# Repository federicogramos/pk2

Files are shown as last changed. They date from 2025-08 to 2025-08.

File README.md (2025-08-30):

# About
Diseño de hardware de programador pk2, una version eliminando lo que no es indispensable del circuito original usado por Microchip, de modo que entre en una placa de tamaño no mas grande que un pendrive. El firmware se brinda sin modificaciones del propio Microchip.

## ./sw
- device file editor: herramienta para adicionar cualquier modelo a la lista de dispositivos programables del pk2.
- codigo fuente + firmware para el 18F2550 (PK2V023200.hex).
- código fuente app pk2 v2.61
- app pk2 linea de comando.

## ./pcb
Contiene 2 diseños:
- el del Pickit2
- un zocalo externo para encapsulados DIP.
Del pcb pendrive estoy subiendo unicamente la última version. Tengo otra que fue el 1er prototipo single layer. Si en algun momento a alguien le interesa porque la fabricacion es más simple y no requiere pth, puede solicitarme que la suba.

#### Pk2 pcb top y bottom
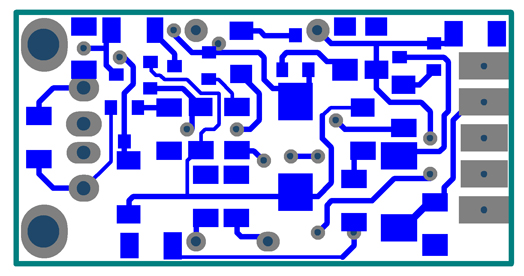
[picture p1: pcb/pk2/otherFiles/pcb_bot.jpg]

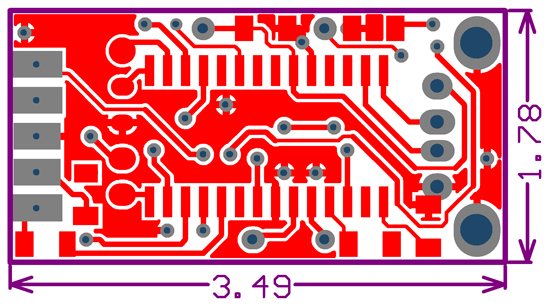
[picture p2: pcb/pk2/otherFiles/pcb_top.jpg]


#### Schematic (pk2 only)
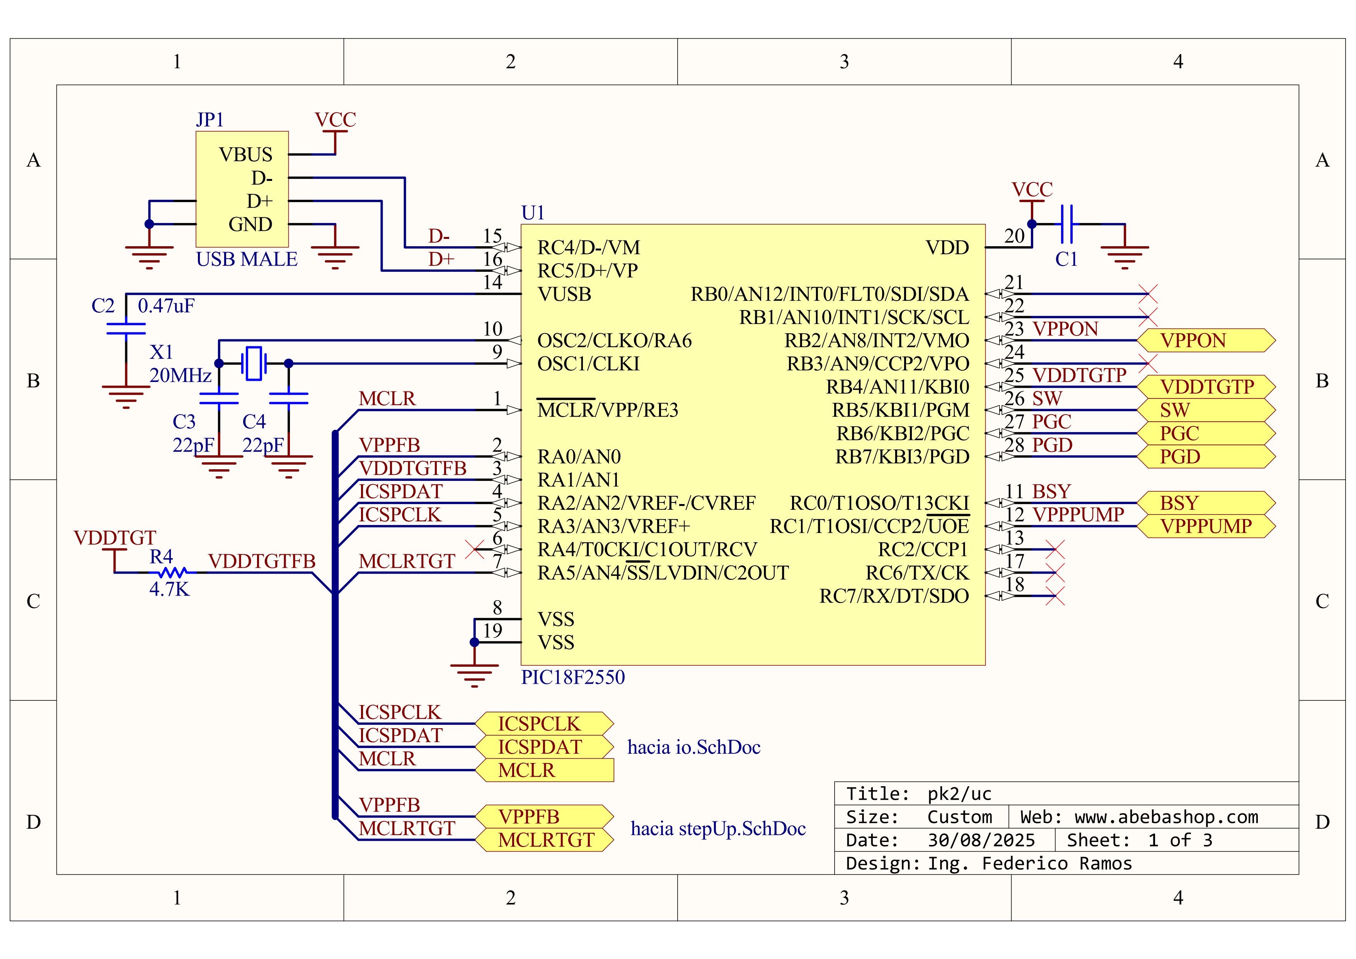
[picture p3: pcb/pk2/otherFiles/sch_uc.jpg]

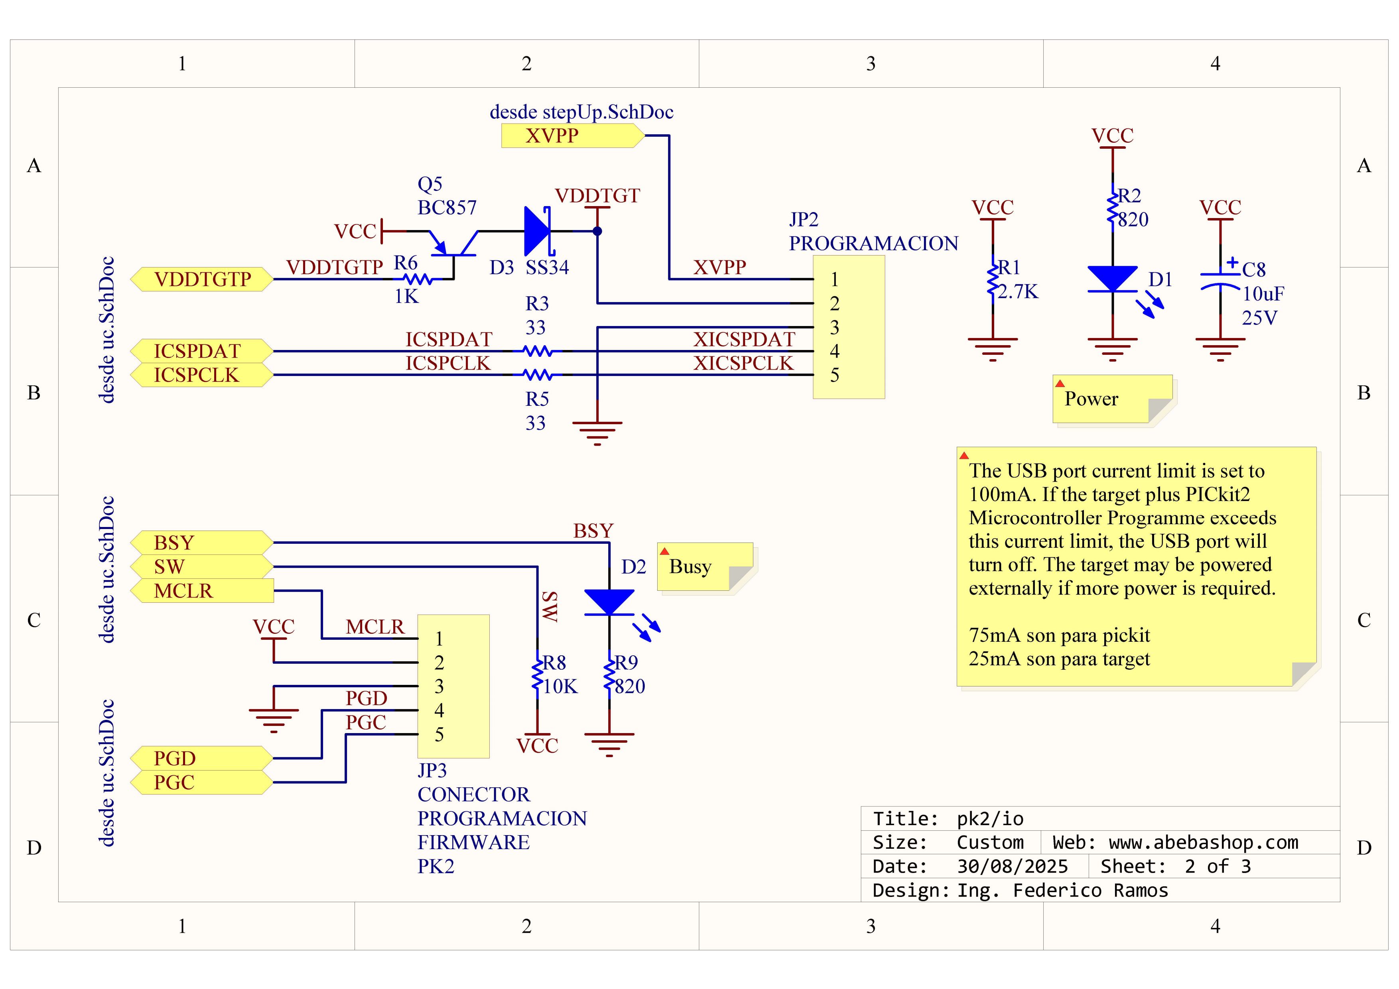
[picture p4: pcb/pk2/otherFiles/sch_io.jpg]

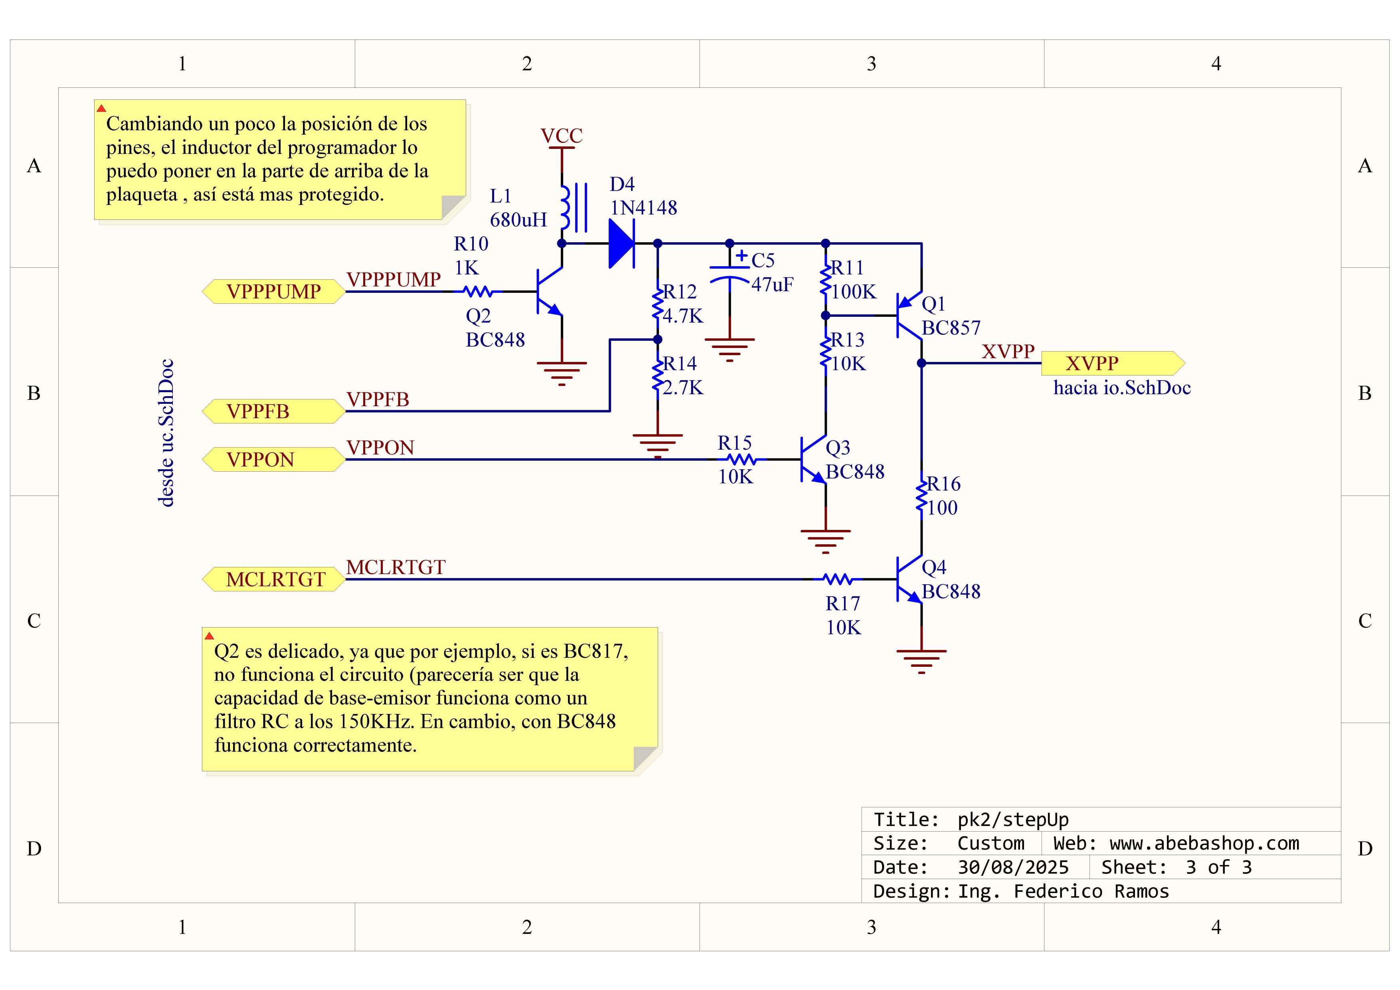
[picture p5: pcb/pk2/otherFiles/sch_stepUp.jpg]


#### Prototipo top y bottom
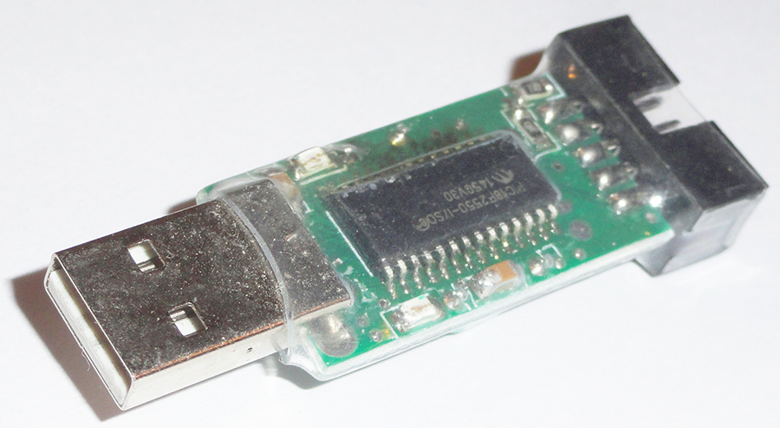
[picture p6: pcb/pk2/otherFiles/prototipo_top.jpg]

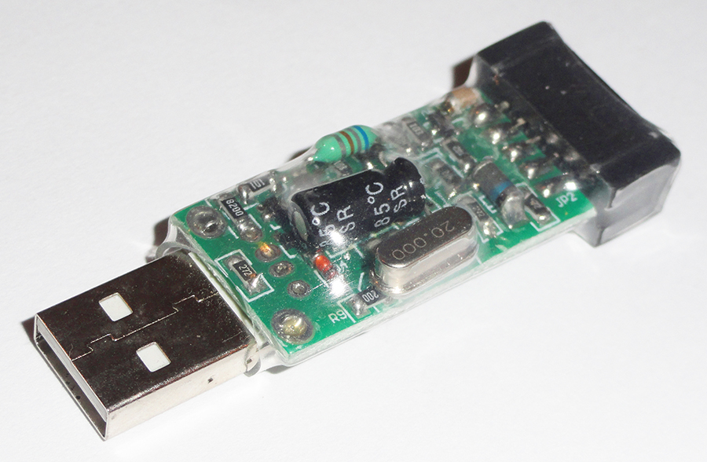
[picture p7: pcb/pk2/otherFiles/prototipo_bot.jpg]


## ./manual
Obsoleto. Antiguamente se entregaba con el dispositivo.

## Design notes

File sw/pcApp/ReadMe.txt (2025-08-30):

Source Notes for PICkit(R) 2 Microcontroller Programmer PC Application v2.60.01

Contains Device File V1.61.00 as
\PICkit2V2\PICkit2V2\bin\Release\PK2DeviceFile.dat

This source project can be opened and modified in Microsoft Visual C# Express 2005.
It requires installation of the Microsoft .NET Framework 2.0

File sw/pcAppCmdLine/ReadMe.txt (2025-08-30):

Source Notes for PICkit(R) 2 Microcontroller Programmer PK2CMD Command Line Interface v1.20

Contains Device File V1.55.00 as
pk2cmd\release\PK2DeviceFile.dat

This source project can be opened and modified in Microsoft Visual C++ 2005 Express.

The included Source Guide is written more for the PICkit 2 Programmer GUI sofware, but generally applies to the PK2CMD source as well.  (Note that PK2CMD does not make any use the INI file described therein.)
NOTE: Descriptions in the Device File section regarding 9th config word support are not applicable to PK2CMD v1.20 as it does not yet support 9 configuration word devices.

This source is set up for Windows development of PK2CMD in Visual Studio, although all source files necessary for Linux and Mac OS builds are also included.  However, for building on these OS's it is recommended to download the v1.20 source titled specifically for them, as that archive contains a makefile and documentation specific to those Operating Systems.

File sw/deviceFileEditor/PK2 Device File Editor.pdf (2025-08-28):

# PICkit 2 Device Data File Editor

This program provides a simple interface for editing the device data file PKDeviceFile.dat that comes with the PICkit2 windows programs. It's my first .NET application ever and I won't be surprised if there's a few bugs in it.

I know this is a painfully simple program which probably doesn't require any documentation whatsoever, so only basic notes are provided.

## Program screenshot:

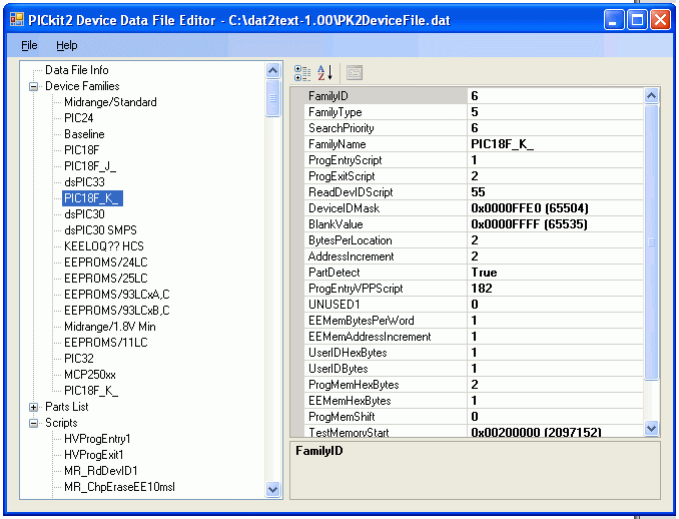
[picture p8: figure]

## Usage

File Menu:
Open - loads and decodes file

Save - overwrites the loaded file with the data in memory
Save As - writes the data in memory to a file of your choosing

Right click on any leaf node (in the left treeview panel) for a popup menu to: Duplicate - make an identical copy of the selected family/part/script
Remove - delete the selected family/part/script

Number formats:
- where a field is displayed as hex (dec), you can enter Hex: e.g. 0xfa44 or &hfa44 or fa44h
Binary: e.g. 0b11110010 or %11110010
Decimal: e.g. 1443
- where a field is displayed as decimal, you can enter Hex: e.g. 0xfa44 or &hfa44
Decimal: e.g. 1443

The program is generally only useful for adding new parts not currently supported by the devicefile bundled with the PICKit 2. The process, after opening the devicefile, is simply to choose an existing PIC from the list of devices, right click on it and select Duplicate Item. There will now be a copy of the part you selected. Change the properties of the new part, including the part name, to appropriate values for the new part. Then save the file and you're done.

It's possible to find the appropriate fields from the datasheet and programming specification documents for the particular PIC part. Sometimes it's a little bit hard to find what you're looking for, or to even know what you should be looking for; feel free to ask on the Microchip Forums (in particular under this thread: PK2 Device File Editor Thread); there's some very knowledgeable and experienced members there. (http://www.microchip.com/forums/m473925-p3.aspx)

There is sometimes updates devicefiles available from Microchip (maybe search the Microchip forums). (http://forum.microchip.com/)

## Downloads

If you already have the .NET 2.0 framework and the VC9 redistributable dll files installed (either in the windows\system32 directory, or in the same directory of this program) you can just download the exe and dll files and the program should run. Or you can use an installer (which I haven't bothered to include for later builds - it's not needed, just copy the exe and dll to the same directory and it should run; provided the VC runtime files are present on the PC).

N.B. VC Runtime files are not required from version 1.0.0.6 onwards.

Version 1.0.0.6 Exe only (.NET 2.0) (https://sites.google.com/site/pk2devicefileeditor/home/files)
Notes: RawConvert.dll (a 32-bit library) dependency has been removed which may allow the program to run under 64 bit Windows.

Version 1.0.0.5 Exe + Dll only (.NET 2.0) (https://sites.google.com/site/pk2devicefileeditor/home/files)
Notes: The serialization bug introduced in 1.0.0.4 has been fixed. DeviceID field is also now displayed as 0xHEX (DEC).

Version 1.0.0.4 Exe + Dll only (.NET 2.0) (https://sites.google.com/site/pk2devicefileeditor/home/files)

Notes: All fields that look like they should be hex are displayed as 0xHEX (DEC); values can be entered as decimal, hex (prefix "0x" or "&H" or suffix "H") or binary (prefix "0b" or "%"). The ScriptLength field is now automatically updated as you change script command array.

Version 1.0.0.3 Exe + Dll only (.NET 2.0) (https://sites.google.com/site/pk2devicefileeditor/home/files)

Notes: The Parts List tree view section is sorted by name. Duplication now actually copies the object data (not just the reference). Fixed the collection explosion bug (probably added some new ones)

Version 1.0.0.2 Installer (.NET 2.0) (https://sites.google.com/site/pk2devicefileeditor/home/files) Version 1.0.0.2 Exe + Dll (.NET 2.0) (https://sites.google.com/site/pk2devicefileeditor/home/files)

Notes: Same as 1.0.0.1, but had to do some mods to let it compile under .NET 2.0 (required to run on the old W2k)

Version 1.0.0.1 Installer (.NET 3.5) (https://sites.google.com/site/pk2devicefileeditor/home/files) Version 1.0.0.1 Exe + Dll (.NET 3.5) (https://sites.google.com/site/pk2devicefileeditor/home/files)

Notes: Proof of concept

Version 1.0.0.0 (.NET 3.5)

Notes: I lost it. It was rubbish anyway so I guess it wasn't really a loss.

MS VC++ Redistributable DLLs (https://sites.google.com/site/pk2devicefileeditor/home/files)
Notes: You may need to download these and extract them to the same directory that you extracted the above .exe + .dll to. Only required if you don't already have them on your PC.

## Bugs (that I know of)

1. Version 1.0.0.3+. Fixed: You'll get a warning if you try to change the configMask & configBlank & script dimensions.
Versions 1.0.0.0 - 1.0.0.2. Workaround: User takes some responsibility for their actions (am I dreaming?) When editing data arrays from the properties editor dialogue, it's possible to add and remove items from the array (and consequently change its size). This could forseeably create an invalid file.
2. Version 1.0.0.3+. Fixed: LeafInfoNode object is now serializable and is cloned for the duplicate operation
Versions 1.0.0.0 - 1.0.0.2. Workaround: you could duplicate all the nodes you want, save the file, then reopen it and edit the nodes
Using the duplicate function creates a new tree node but the actual data is shared between the new node and the old node
3. Version 1.0.0.3+. Fixed: Cut & paste error - I was adding new items to the collections as I was writing them to the file (dumb!)
Versions 1.0.0.0 - 1.0.0.2. Workaround: Just reopen the file, redo the changes and hopefully it works this time.
When duplicating and/or removing nodes after saving a file the number of objects in the families, parts lists and scripts collections double. It only happens after saving the file (which appends to the collections) and then performing a duplicate/remove (which updates the count of items that will later be written to file)
4. Version 1.0.0.5+. Fixed: marked types as serializable
Version 1.0.0.4. int16_t and int32_t data types were not marked as serializable - this meant duplicating an item wasn't possible

Found any new bugs? Please tell me.

## Enhancements

- none planned

## Contact

For info on the PK2 device data file and what to do with it, try the Microchip forums (http://forum.microchip.com/), or more simply PK2 Device File Editor Thread (probably how you found this page) (http://www.microchip.com/forums/m473925-p3.aspx)

To contact me you can try

Sign in (https://www.google.com/a/UniversalLogin?service=jotspot) | Recent Site Activity (https://sites.google.com/site/pk2devicefileeditor/system/app/pages/recentChanges) | Report Abuse (https://sites.google.com/site/pk2devicefileeditor/system/app/pages/reportAbuse) | Print Page | Powered By Google Sites (http://sites.google.com/)

## Comments

You do not have permission to add comments.

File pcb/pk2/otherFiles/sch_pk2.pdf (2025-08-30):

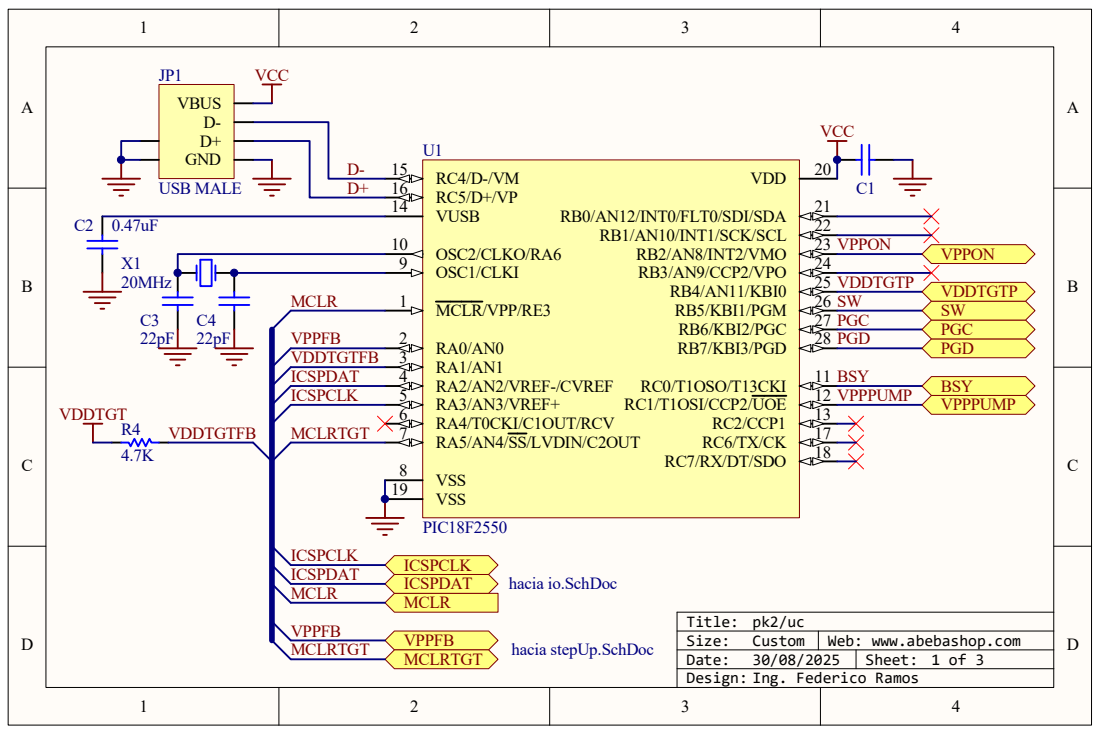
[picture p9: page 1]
MCLR/VPP/RE3 1; RA0/AN0 2 RA1/AN1 3 RA2/AN2/VREF-/CVREF 4 RA3/AN3/VREF+ 5 RA4/T0CKI/C1OUT/RCV 6 RA5/AN4/SS/LVDIN/C2OUT 7; VSS 8; OSC1/CLKI 9; OSC2/CLKO/RA6 10; RC0/T1OSO/T13CKI; RC1/T1OSI/CCP2/UOE; RC2/CCP1; VUSB 14; RC7/RX/DT/SDO; VSS 19; VDD; RB0/AN12/INT0/FLT0/SDI/SDA; RB1/AN10/INT1/SCK/SCL; RB2/AN8/INT2/VMO; RB3/AN9/CCP2/VPO; RB4/AN11/KBI0; RB5/KBI1/PGM; RB6/KBI2/PGC; RB7/KBI3/PGD; PIC18F2550; VCC; 20MHz; VDDTGT; MCLR; PGD; PGC; BSY; VPPFB VDDTGTFB ICSPDAT ICSPCLK; MCLRTGT; VPPON; VPPPUMP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

hacia io.SchDoc

Web: www.abebashop.com

hacia stepUp.SchDoc

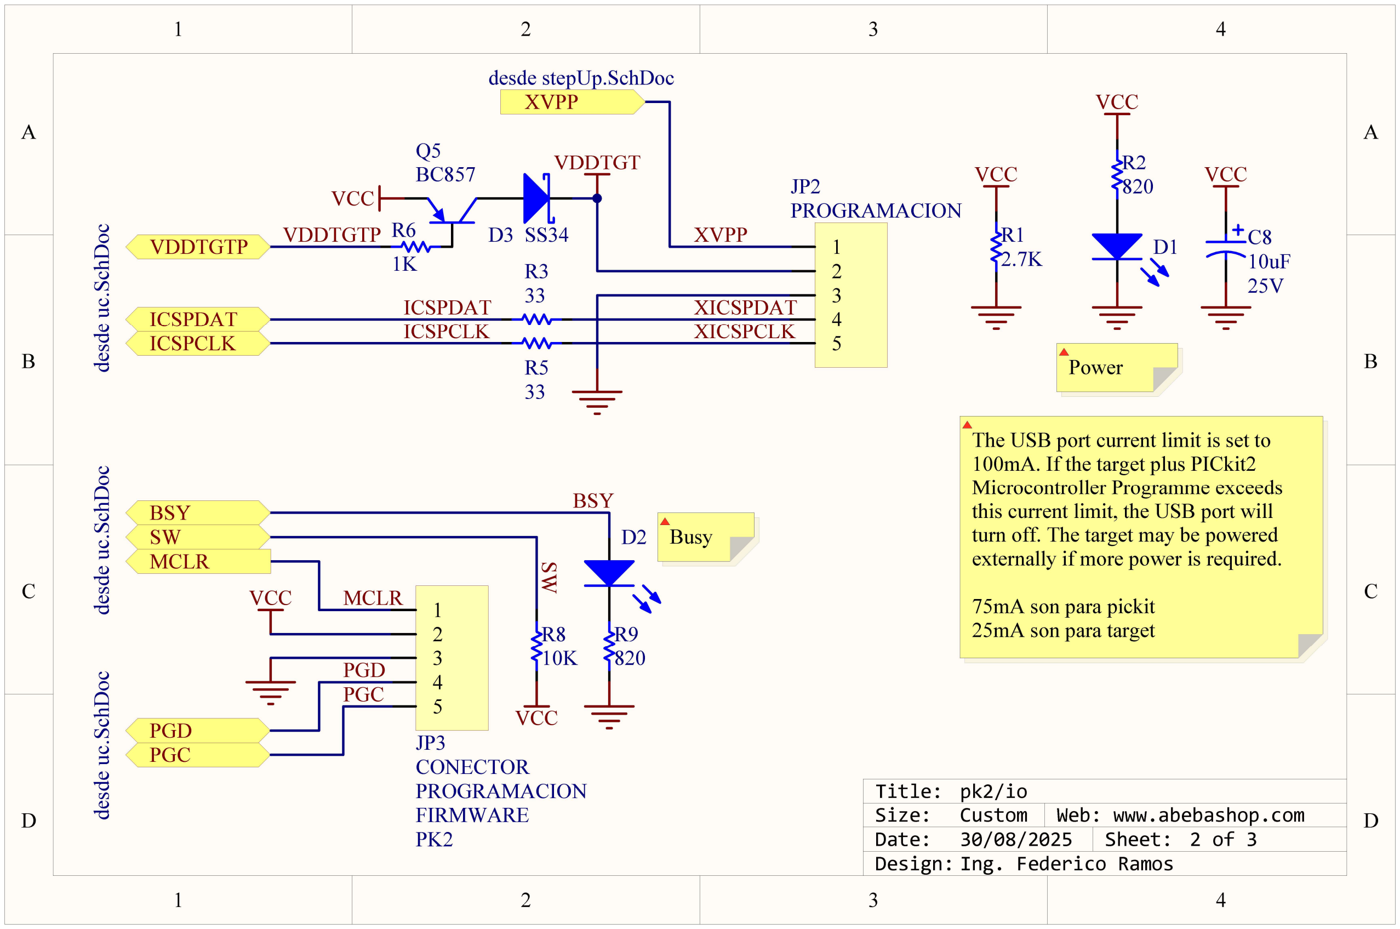
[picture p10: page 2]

D D

C C

B B

A A

VCC | MCLR
| PGD PGC

820

R9

D2

BSY SW

10K

R8

VCC

CONECTOR

1
2
3
4
5

PROGRAMACION
FIRMWARE
PK2

JP3

820

R2

D1

VCC

2.7K

R1

VCC

10uF
25V

C8

VCC

33

R5

33

R3

ICSPCLK

ICSPDAT

VDDTGT

XVPP

XICSPDAT
XICSPCLK

Q5
BC857

VDDTGTP

VCC

1K

R6 D3 SS34

PROGRAMACION
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
MCLR

SW

BSY

VDDTGTP

ICSPDAT
ICSPCLK

XVPP desde uc.SchDoc desde uc.SchDoc desde uc.SchDoc

desde stepUp.SchDoc

Title:
Size:
Date: | Sheet:
Design:

30/08/2025

| Web: www.abebashop.com
| Ing. Federico Ramos

### 2 of 3

pk2/io
Custom

Busy

Power

The USB port current limit is set to 100mA. If the target plus PICkit2 Microcontroller Programme exceeds this current limit, the USB port will turn off. The target may be powered externally if more power is required.

75mA son para pickit
25mA son para target

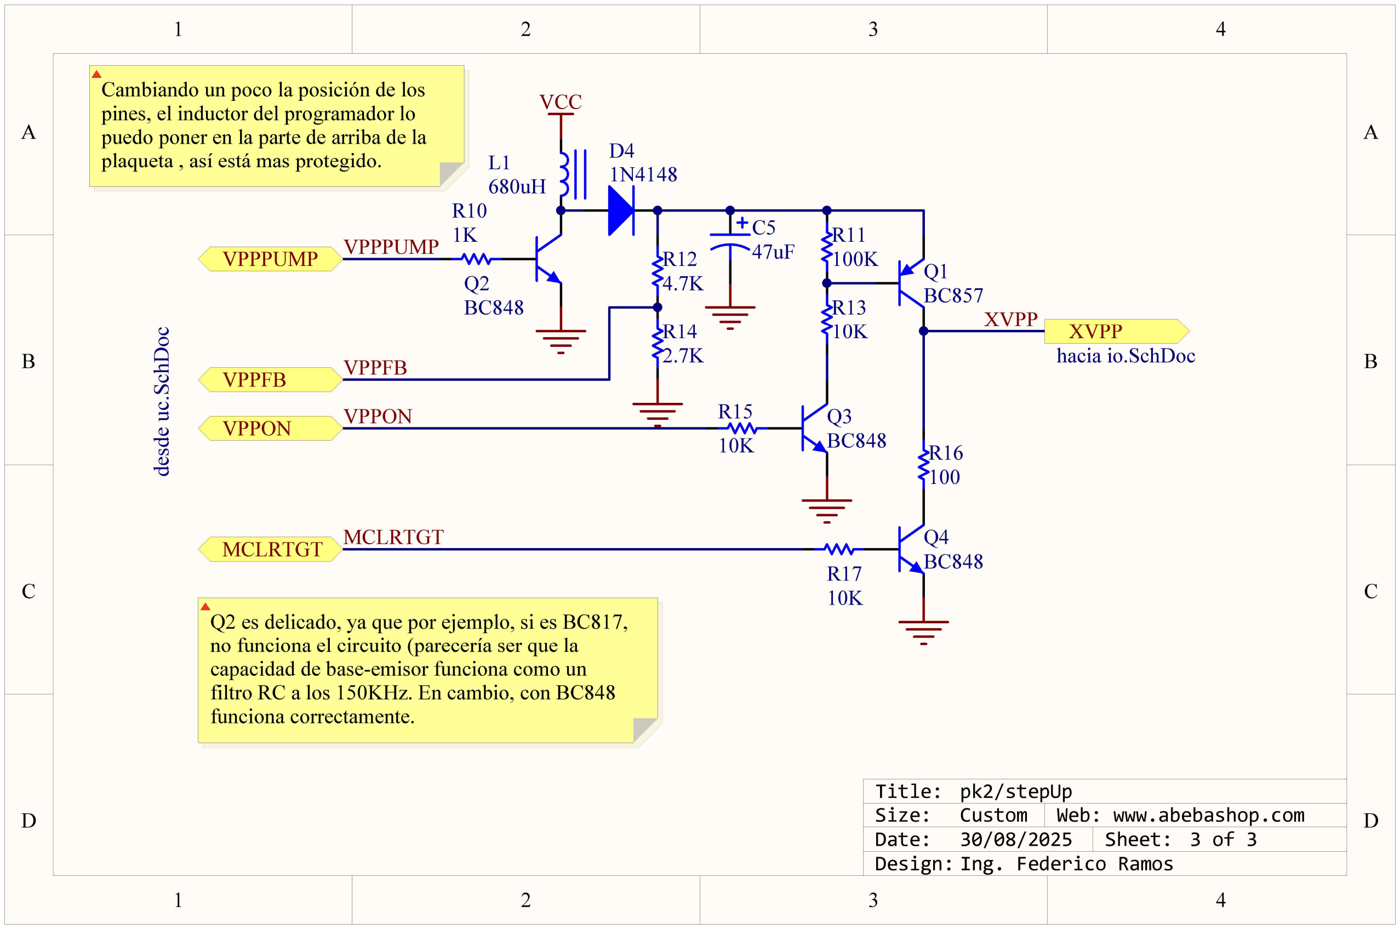
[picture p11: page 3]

D D

C C

B B

A A

680uH

L1

Q2
BC848

1K

R10
VPPPUMP
4.7K

R12

2.7K

R14
VPPFB

100K

R11

10K

R13

Q1
BC857

Q3
10K | BC848
VPPON | R15

100

R16

Q4
BC848
10K

R17

MCLRTGT

D4
1N4148

VCC

C5
47uF

XVPP

VPPPUMP

VPPFB

VPPON

MCLRTGT

XVPP
hacia io.SchDoc desde uc.SchDoc

Title:
Size:
Date: | Sheet:
Design:

30/08/2025

| Web: www.abebashop.com
| Ing. Federico Ramos

### 3 of 3

pk2/stepUp
Custom

Q2 es delicado, ya que por ejemplo, si es BC817, no funciona el circuito (parecería ser que la capacidad de base-emisor funciona como un filtro RC a los 150KHz. En cambio, con BC848 funciona correctamente.

Cambiando un poco la posición de los pines, el inductor del programador lo puedo poner en la parte de arriba de la plaqueta , así está mas protegido.

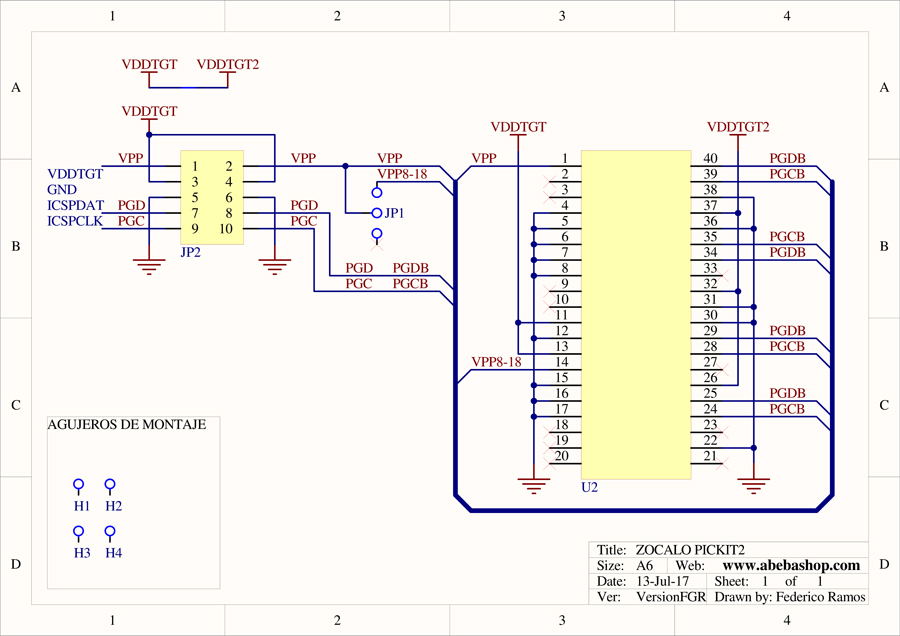
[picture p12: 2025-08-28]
pcb/pk2socket/otherFiles/WEBDOC_IX00000002_N0016.jpg

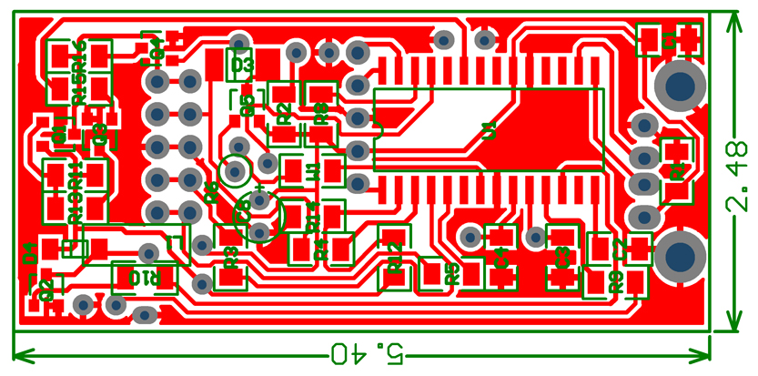
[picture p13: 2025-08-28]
pcb/pk2/otherFiles/WEBDOC_IX00000002_N0001.jpg

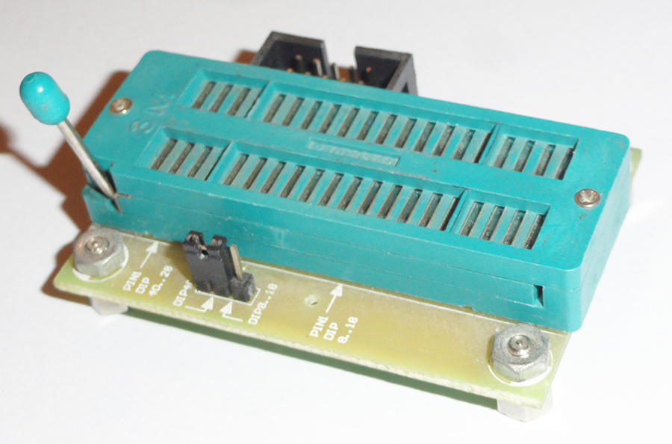
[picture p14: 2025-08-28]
pcb/pk2socket/otherFiles/WEBDOC_IX00000002_N0017.jpg

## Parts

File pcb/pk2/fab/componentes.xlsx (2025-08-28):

Description | Designator | Quantity [x1] | Quantity [x77]
BC846A | Q2, Q3, Q4 | 3 | 372
BC856A | Q1, Q5 | 2 | 248
Capacitor 1206 / 100nF | C1 | 1 | 124
Capacitor 1206 / 470nF | C2 | 1 | 124
Capacitor 1206 / 22pF | C3, C4 | 2 | 248
Capacitor 1206 / 1uF | C8 | 1 | 124
Cristal 20Mhz / HC49S | X1 | 1 | 124
PIC18F2550 | U1 | 1 | 124
IDC Header 5x1 Recto | JP2 | 1 | 124
1N4148 SMD | D4 | 1 | 124
Inductor 680uHy | L1 | 1 | 124
Led 1206 Rojo | D1? | 1 | 124
Led 1206 Amarillo | D2? | 1 | 124
Resistor 1206 / 2.7K | R1, R14 | 2 | 248
Resistor 1206 / 100K | R11 | 1 | 124
Resistor 1206 / 100 | R16 | 1 | 124
Resistor 1206 / 820 | R2, R9 | 2 | 248
Resistor 1206 / 33 | R3, R5 | 2 | 248
Resistor 1206 / 4.7K | R4, R12 | 2 | 248
Resistor 1206 / 1K | R6, R10 | 2 | 248
Resistor 1206 / 10K | R8, R13, R15, R17 | 4 | 496
SS34 | D3 | 1 | 124
Capacitor Electrolitico 47uF / 16V | C5 | 1 | 124
PCB USB 'A' Connector Male | JP1 | 1 | 124

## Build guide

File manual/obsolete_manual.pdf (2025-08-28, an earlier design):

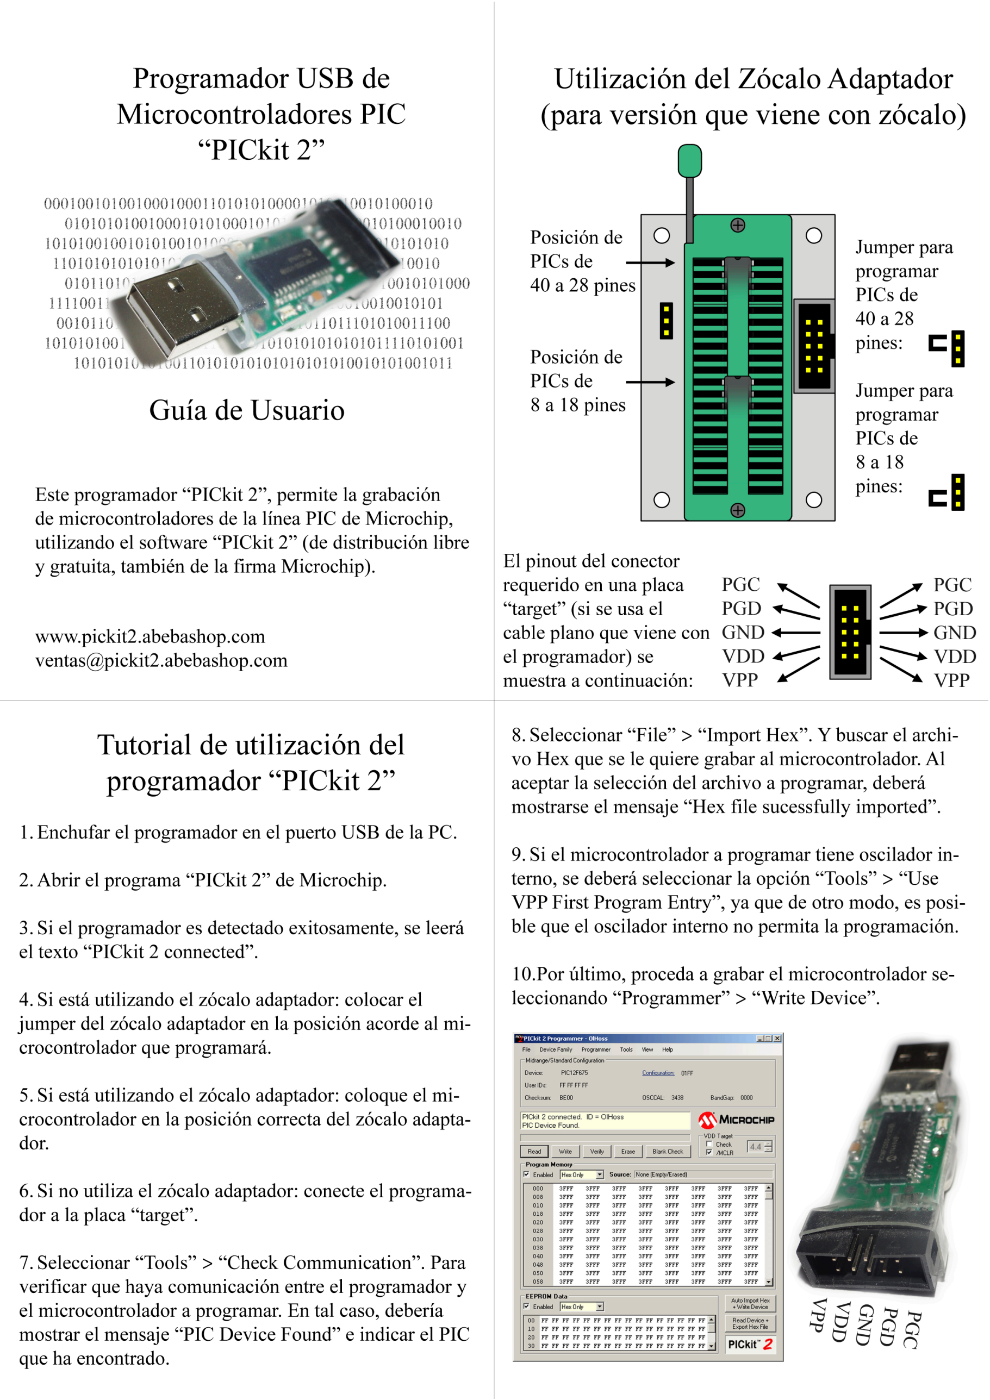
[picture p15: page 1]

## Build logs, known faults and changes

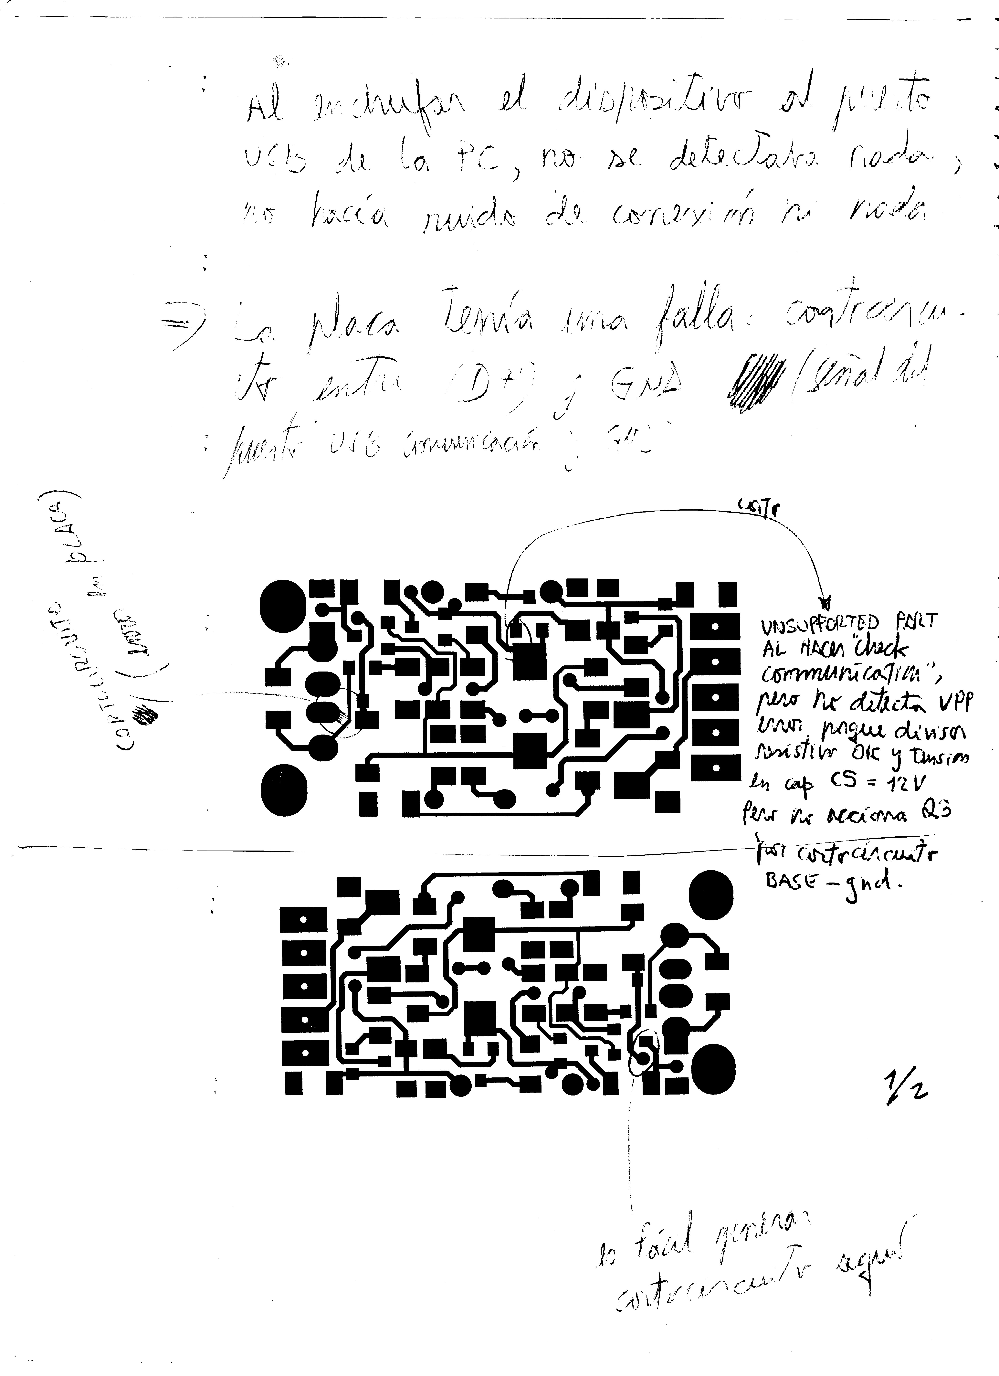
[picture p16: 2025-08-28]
pcb/pk2/buildNotes/debug_notes_0.jpg

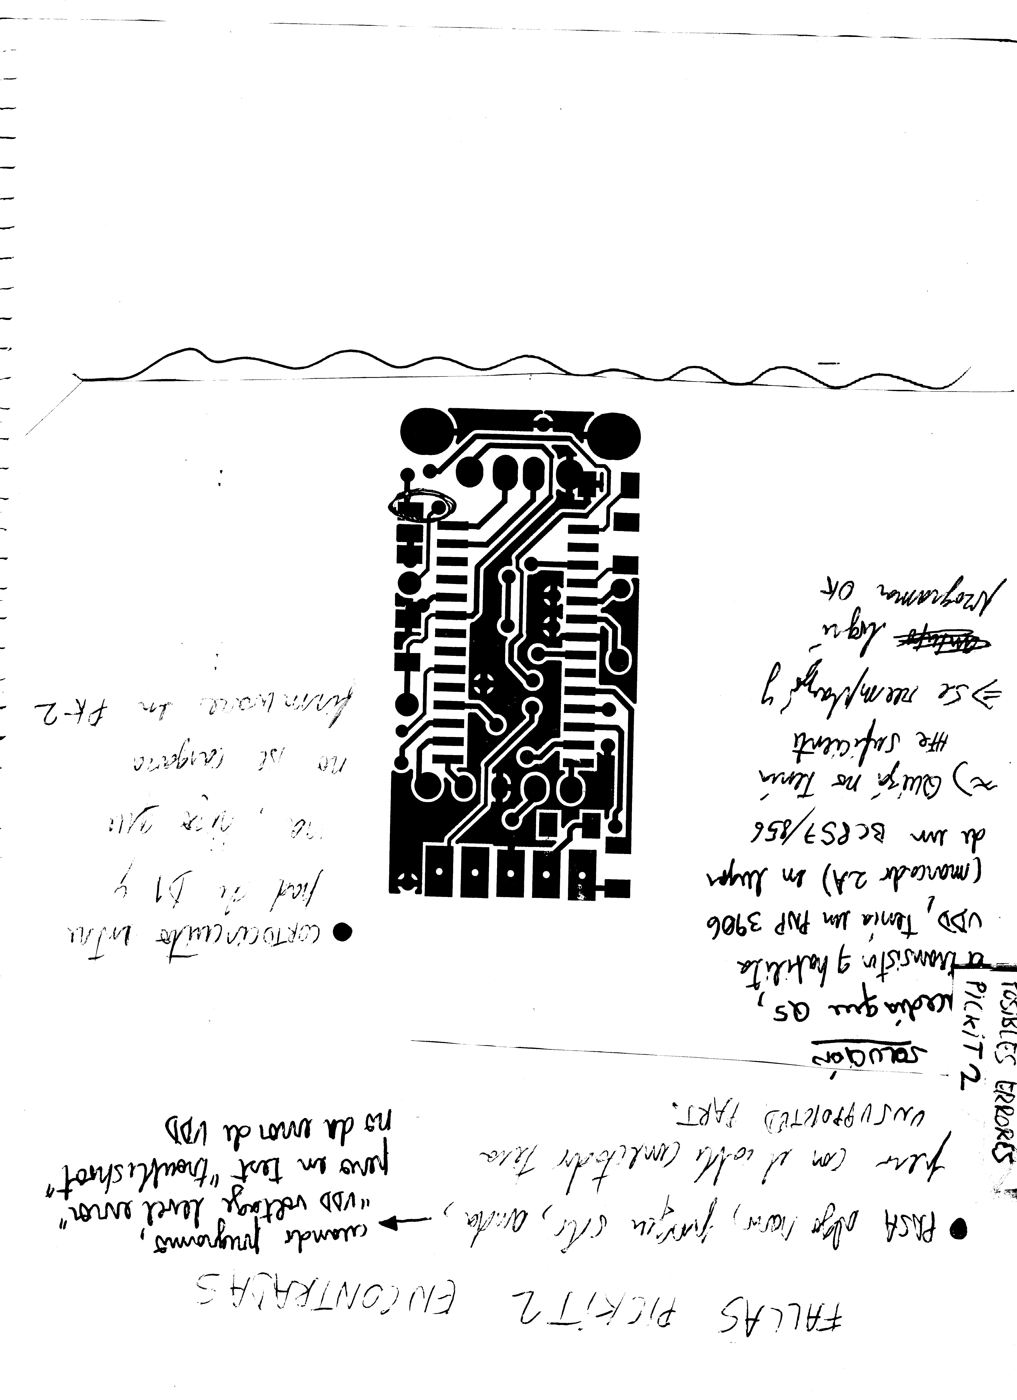
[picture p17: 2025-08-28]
pcb/pk2/buildNotes/debug_notes_2.jpg

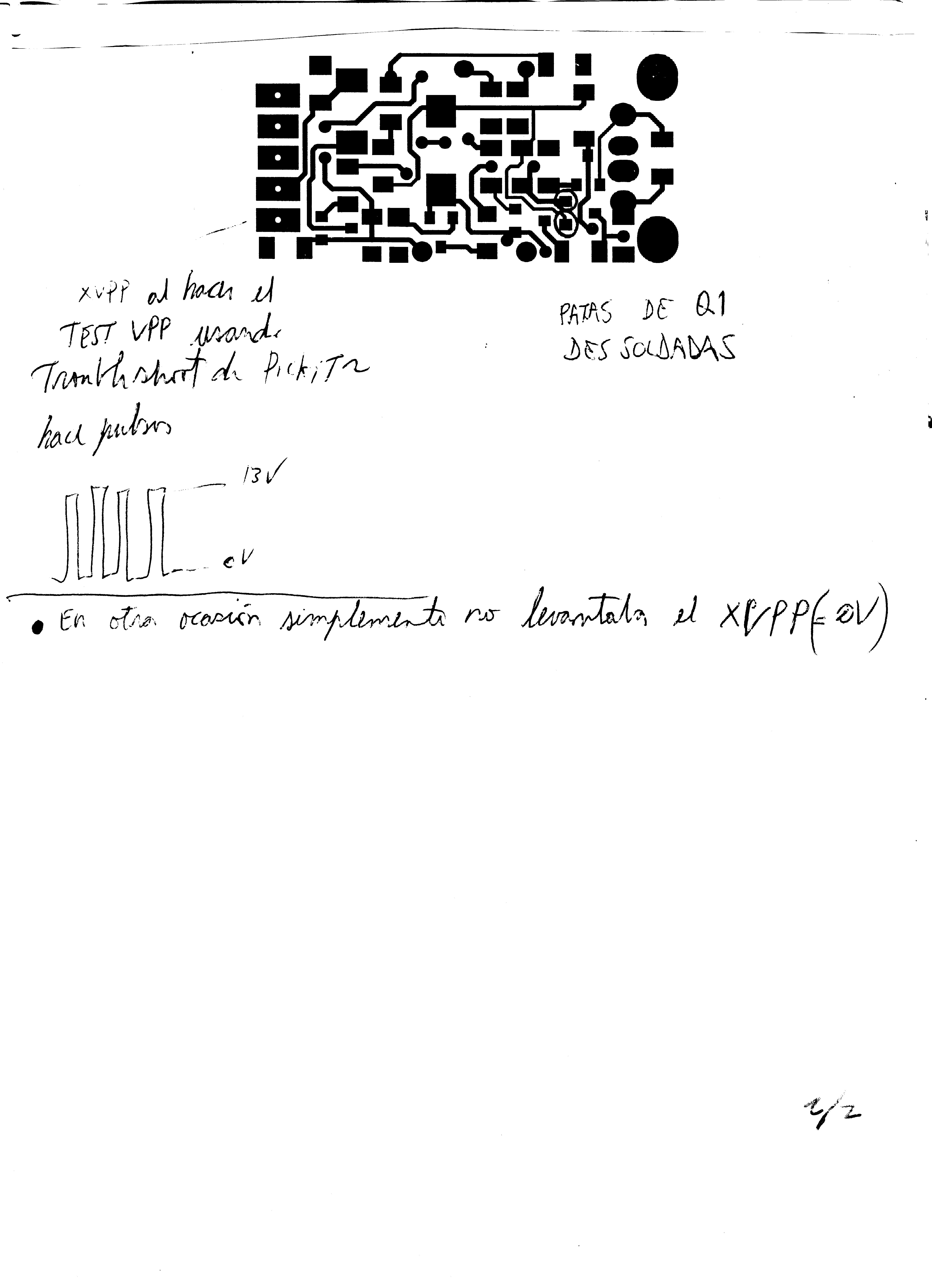
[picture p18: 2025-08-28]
pcb/pk2/buildNotes/debug_notes_1.jpg

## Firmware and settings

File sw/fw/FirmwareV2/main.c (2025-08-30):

/*********************************************************************
 *
 *                Microchip USB C18 Firmware
 *
 *********************************************************************
 * FileName:        main.c
 * Dependencies:    See INCLUDES section below
 * Processor:       PIC18
 * Compiler:        C18 3.00
 * Company:         Microchip Technology, Inc.
 *
 * Software License Agreement
 *
 * The software supplied herewith by Microchip Technology Incorporated
 * (the “Company”) for its PICmicro® Microcontroller is intended and
 * supplied to you, the Company’s customer, for use solely and
 * exclusively on Microchip PICmicro Microcontroller products. The
 * software is owned by the Company and/or its supplier, and is
 * protected under applicable copyright laws. All rights are reserved.
 * Any use in violation of the foregoing restrictions may subject the
 * user to criminal sanctions under applicable laws, as well as to
 * civil liability for the breach of the terms and conditions of this
 * license.
 *
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
 * Author               Date        Comment
 *~~~~~~~~~~~~~~~~~~~~~~~~~~~~~~~~~~~~~~~~~~~~~~~~~~~~~~~~~~~~~~~~~~~~
 * Rawin Rojvanit       7/21/04     Original
 * Steven Bible      2005-04-20     Version 1 Released
 ********************************************************************/

/** I N C L U D E S **********************************************************/

#include <p18cxxx.h>
#include "system\typedefs.h"                        // Required
#include "system\usb\usb.h"                         // Required
#include "io_cfg.h"                                 // Required

#include "system\usb\usb_compile_time_validation.h" // Optional
#include "user\pickit.h"
#include "user\pk_isr.h"


/** V A R I A B L E S ********************************************************/

#pragma udata


/** P R I V A T E  P R O T O T Y P E S ***************************************/

static void InitializeSystem(void);
void USBTasks(void);


/** V E C T O R  R E M A P P I N G *******************************************/

extern void _startup (void);        // See c018i.c in your C18 compiler dir
#pragma code _RESET_INTERRUPT_VECTOR = 0x002000
void _reset (void)
{
    _asm goto _startup _endasm
}

#pragma code _HIGH_INTERRUPT_VECTOR = 0x002008
void _high_ISR (void)
{
    _asm
        goto InterruptHandler       // jump to interrupt routine
    _endasm
}

#pragma code InterruptVectorLow = 0x002018
void InterruptVectorLow (void)
{
    _asm
        goto InterruptHandler       // jump to interrupt routine
    _endasm
}


/** D E C L A R A T I O N S **************************************************/

#pragma code


/******************************************************************************
 * Function:        void main(void)
 *
 * PreCondition:    None
 *
 * Input:           None
 *
 * Output:          None
 *
 * Side Effects:    None
 *
 * Overview:        Main program entry point.
 *
 * Note:            None
 *****************************************************************************/
void main(void)
{
    InitializeSystem();

    while(1) {

        //USBTasks();         // USB Tasks
        USBDriverService();                 // polling method
        ProcessIO();        // See user\pickit.c & .h

    } // end while

} // end main


/******************************************************************************
 * Function:        static void InitializeSystem(void)
 *
 * PreCondition:    None
 *
 * Input:           None
 *
 * Output:          None
 *
 * Side Effects:    None
 *
 * Overview:        InitializeSystem is a centralize initialization routine.
 *                  All required USB initialization routines are called from
 *                  here.
 *
 *                  User application initialization routine should also be
 *                  called from here.                  
 *
 * Note:            None
 *****************************************************************************/
static void InitializeSystem(void)
{
    
    #if defined(USE_USB_BUS_SENSE_IO)       // see usbcfg.h
        tris_usb_bus_sense = INPUT_PIN;     // See io_cfg.h
    #endif
    
    #if defined(USE_SELF_POWER_SENSE_IO)    // see usbcfg.h
        tris_self_power = INPUT_PIN;
    #endif
    
    mInitializeUSBDriver();                 // See usbdrv.h
    
    PICkitInit();                           // See pickit.c and pickit.h

    USBCheckBusStatus(); 

} // end InitializeSystem



/*****************************************************************************
 * The following is a value stored in upper program memory to let the boot-
 * loader know if an application program is loaded.  If the bootloader does
 * not read this code, it jumps to bootloader mode.
 ****************************************************************************/

//#pragma romdata _bootcode = 0x7FFE
//rom word bootcode = 0x5555;

/** EOF main.c ***************************************************************/

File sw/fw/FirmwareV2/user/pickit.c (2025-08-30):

/*********************************************************************
 *
 *                  Microchip PICkit 2 v2 Flash Starter Kit
 *
 *********************************************************************
 * FileName:        pickit.c
 * Dependencies:    See INCLUDES section below
 * Processor:       PIC18
 * Compiler:        C18 3.00
 * Company:         Microchip Technology, Inc.
 *
 * Software License Agreement
 *
 * The software supplied herewith by Microchip Technology Incorporated
 * (the “Company”) for its PICmicro® Microcontroller is intended and
 * supplied to you, the Company’s customer, for use solely and
 * exclusively on Microchip PICmicro Microcontroller products. The
 * software is owned by the Company and/or its supplier, and is
 * protected under applicable copyright laws. All rights are reserved.
 * Any use in violation of the foregoing restrictions may subject the
 * user to criminal sanctions under applicable laws, as well as to
 * civil liability for the breach of the terms and conditions of this
 * license.
 *
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
 * Author               Date        Comment
 *~~~~~~~~~~~~~~~~~~~~~~~~~~~~~~~~~~~~~~~~~~~~~~~~~~~~~~~~~~~~~~~~~~~~
 * Steven Bible      2004-11-04     Initial Write
 * Steven Bible      2005-04-20     Version 1 Released
 * Walter Kicinski   2006-May-15    Rewrite for v2
 ********************************************************************
 * Change log
 * v2.01 - WK - 
 *       initial v2 release
 * v2.02 - WK - May 2007
 *       Ensures BOR bits in CONFIG2L are disabled at reset
 * v2.10 - WK - Jun 2007
 *       Added ShiftBitsOutICSPHold(), and new script commands
 *          WRITE_BITS_LIT_HLD, WRITE_BITS_BUF_HLD
 *       Added new script commands to support Serial EEPROM devices:
 *          SET_AUX, AUX_STATE_BUFFER, I2C_START, I2C_STOP,
 *          I2C_WR_BYTE_LIT, I2C_WR_BYTE_BUF, I2C_RD_BYTE_ACK, 
 *          I2C_RD_BYTE_NACK, SPI_WR_BYTE_LIT, SPI_WR_BYTE_BUF,
 *          SPI_RD_BYTE_BUF
 *       Added new commands for calibration and internal EEPROM
 *          SET_VOLTAGE_CALS, WR_INTERNAL_EE, RD_INTERNAL_EE
 *       Added Serial Mode support and commands
 *          ENTER_UART_MODE, EXIT_UART_MODE
 * v2.20 - WK - Jul 2007
 *      Updated USB stack to v1.3
 *      Added ICDSlaveBL_transmit & ICDSlaveBL_Receive to handle new
 *      handshaking for baseline debug to get around 16F50x-ICD ICD pins
 *      drive issues.
 * v2.30 - WK - Apr 2008
 *      Removed USB serial number to allow multiple units on one PC
 *      No longer calls EnsureBOROff() at reset (may have been causing
 *                a dead PICkit 2 issue with USB VREG off)
 *      Added MEASURE_PULSE script command
 *      Added UNIO_TX and UNIO_TX_RX script commands
 *      UARTModeService() now monitors VDD, and shuts off if below voltage.
 *                However, no error / indication is set.
 *      Modified USB stack to free up space from unused/unneeded portions
 *      Added Programmer-To-Go support
 *      Added Logic Analyzer
 * v2.30.01 - WK - Apr 2008
 *      Fixed issue in I2C_Read() with duplicate lables in different
 *      ASM sections.
 * v2.31.00 - WK - Jun 2008
 *      Fixed issue with Programmer-To-Go.  ENTER_LEARN_MODE needs to set
 *      pk2go_memsize.
 *      Added code to jump tables to handle PCLATH and prevent 256-byte
 *      boundary concern.
 * v2.32.00 - WK - July 2008
 *      Now reports the UnitID string as the USB Serial Number string
 *      descriptor.  This was necessary to identify devices via Unit ID
 *      without HID transactions.  The latter can mess up existing
 *      communication links when searching for devices.
 *      Freed up program space by adding ScriptIdxIncJumpEnd.
 *      
 ********************************************************************/

/** I N C L U D E S **********************************************************/
#include <p18cxxx.h>
#include "delays.h"
#include "system\typedefs.h"
#include "system\usb\usb.h"

#include "io_cfg.h"                 // I/O pin mapping
#include "user\pickit.h"
#include "user\pk_isr.h"
#include "user\pk_prog2go.h"

/** V A R I A B L E S ********************************************************/
#pragma udata	ScriptBuffer					// in banks 5,6, & 7.
// NOTE: must use SECTION command in linker script.
unsigned char uc_script_buffer[SCRIPTBUF_SIZE];		// Script Buffer

#pragma udata	USB_Buffers
char inbuffer[BUF_SIZE];            				// input to USB device buffer
char outbuffer[BUF_SIZE];            				// output to USB device buffer

#pragma udata	DownloadBuffer
unsigned char 	uc_download_buffer[DOWNLOAD_SIZE];	// Download Data Buffer

#pragma udata	UploadBuffer
unsigned char 	uc_upload_buffer[UPLOAD_SIZE];		// Upload Data Buffer

#include    "pickit2.inc"
#pragma udata access	AssemblyAccess = INLINE_ASM_RAM
near unsigned char asm_temp1;
near unsigned char asm_temp2;
near unsigned char asm_temp3;
near unsigned char asm_temp4;
near unsigned char asm_temp5;
near unsigned char asm_temp6;
near unsigned char asm_temp7;
near unsigned char asm_temp8;
near unsigned char asm_temp9;
near unsigned char asm_temp10;
near unsigned char asm_temp11;
near unsigned char asm_temp12;

#pragma udata	Misc
unsigned char 	*uc_ScriptBuf_ptr = &uc_script_buffer[0];

struct {						// Script table - keeps track of scripts in the Script Buffer.
	unsigned char	Length;
	int	StartIndex;	// offset from uc_script_buffer[0] of beginning of script.
} ScriptTable[SCRIPT_ENTRIES];

unsigned char icsp_pins;
unsigned char icsp_baud;
unsigned char aux_pin;

struct {
    unsigned char	write_index;        // buffer write index
    unsigned char	read_index;			// buffer read index
    unsigned int    used_bytes;         // # bytes in buffer
} downloadbuf_mgmt;

#pragma udata	Misc2
union {		// Status bits
	struct {
		unsigned char	StatusLow;
		unsigned char	StatusHigh;
	};
	struct{
		// StatusLow
		unsigned VddGNDOn:1;	// bit 0
		unsigned VddOn:1;
		unsigned VppGNDOn:1;
		unsigned VppOn:1;
		unsigned VddError:1;
		unsigned VppError:1;
        unsigned ButtonPressed:1;
		unsigned :1;
		//StatusHigh
        unsigned Reset:1;       // bit 0
		unsigned UARTMode:1;			
        unsigned ICDTimeOut:1;
		unsigned UpLoadFull:1;
		unsigned DownloadEmpty:1;
		unsigned EmptyScript:1;
		unsigned ScriptBufOvrFlow:1;
		unsigned DownloadOvrFlow:1;
	};
} Pk2Status;

struct {
    unsigned char	write_index;		// buffer write index
    unsigned char	read_index;			// buffer read index
    unsigned int    used_bytes;         // # bytes in buffer
} uploadbuf_mgmt; 

#pragma udata	Misc3

struct {
	unsigned char   VddThreshold;	// error detect threshold
	unsigned char   VppThreshold;	// error detect threshold
    unsigned char   VddErrCount;
    unsigned char   VppErrCount;
    unsigned int    BlinkClount;    // counter for blinking Busy on VDD/VPP error
} VddVppLevels;

#pragma udata	Misc4
struct {
	unsigned char CCPRSetPoint;
	unsigned char UppperLimit;
	unsigned char LowerLimit;	
} Vpp_PWM;
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

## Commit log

2025-08-28 docs added para ambos pendrive y zoc
2025-08-28 readme acomodado
    [01.SchDoc, 02.SchDoc, 03.SchDoc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]
2025-08-30 updated sch organization from 1 single file to 3
    [io.SchDoc, pk2.PcbDoc, pk2.PrjPcb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]
